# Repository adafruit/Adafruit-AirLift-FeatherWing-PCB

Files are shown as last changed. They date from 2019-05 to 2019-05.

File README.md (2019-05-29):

# Adafruit-AirLift-FeatherWing-PCB
PCB files for Adafruit AirLift FeatherWing

Format is EagleCAD schematic and board layout

For more details, check out the product page at

   * https://www.adafruit.com/product/4264

Adafruit invests time and resources providing this open source design, 
please support Adafruit and open-source hardware by purchasing 
products from Adafruit!

Designed by Adafruit Industries.  
Creative Commons Attribution, Share-Alike license, check license.txt for more information
All text above must be included in any redistribution

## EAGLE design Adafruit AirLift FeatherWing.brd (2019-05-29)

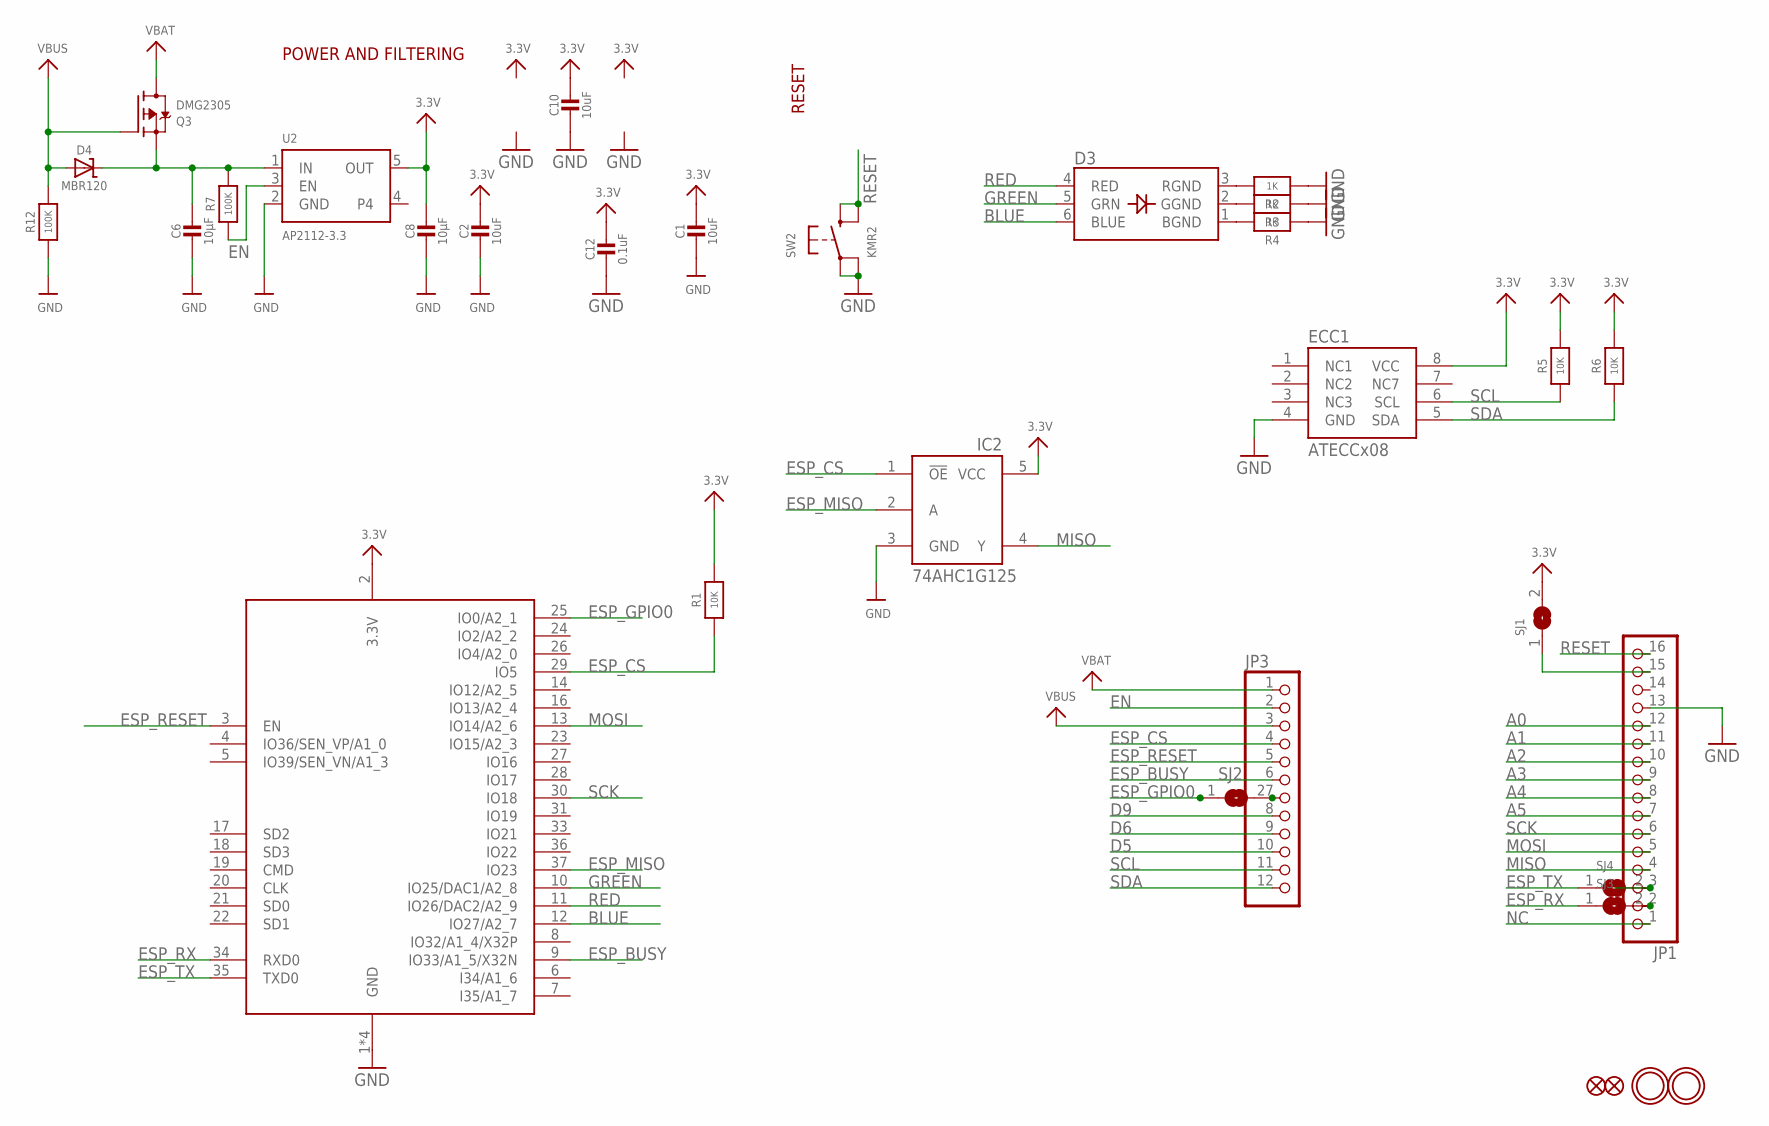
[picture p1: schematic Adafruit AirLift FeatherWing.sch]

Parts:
C1, C2, C10: 10uF; 0805-NO
C6, C8: 10µF; 0805-NO
C12: 0.1uF; 0603-NO
D3: LED_RGB_PLCC6CREE-CLV6A; RGBLED_PLCC6
D4: MBR120; SOD-123
ECC1: ATECCx08; SOIC8
IC2: 74AHC1G125; SOT23-5L
JP1: HEADER-1X16_MIN; 1X16_ROUND_MIN
JP3: HEADER-1X12_MIN; 1X12_ROUND_MIN
Q3: DMG2305; SOT23-R
R1, R5, R6: 10K; 0603-NO
R2, R3, R4: 1K; 0603-NO
R7, R12: 100K; 0603-NO
SJ1, SJ2, SJ3, SJ4: SOLDERJUMPER; SOLDERJUMPER_ARROW_NOPASTE
SW2: KMR2; BTN_KMR2_4.6X2.8
U2: AP2112-3.3; SOT23-5
U$31, U$32: MOUNTINGHOLE2.5; MOUNTINGHOLE_2.5_PLATED
U$34, U$35: FIDUCIAL_1MM
X3: ESP32_WROOM32_SKINNY; WROOM32_SKINNY

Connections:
3.3V: C1.1, C2.1, C8.1, C10.1, C12.1, ECC1.8 (VCC), IC2.5 (VCC), R1.2, R5.2, R6.2, SJ1.2, U2.5 (OUT), X3.2 (3.3V)
A0: JP1.12
A1: JP1.11
A2: JP1.10
A3: JP1.9
A4: JP1.8
A5: JP1.7
BLUE: D3.6 (BLUE), X3.12 (IO27/A2_7)
D5: JP3.10
D6: JP3.9
D9: JP3.8
EN: JP3.2, R7.1, U2.3 (EN)
ESP_BUSY: JP3.6, X3.9 (IO33/A1_5/X32N)
ESP_CS: IC2.1 (!OE), JP3.4, R1.1, X3.29 (IO5)
ESP_GPIO0: SJ2.1, X3.25 (IO0/A2_1)
ESP_MISO: IC2.2 (A), X3.37 (IO23)
ESP_RESET: JP3.5, X3.3 (EN)
ESP_RX: SJ3.1, X3.34 (RXD0)
ESP_TX: SJ4.1, X3.35 (TXD0)
GND: C1.2, C2.2, C6.2, C8.2, C10.2, C12.2, ECC1.4 (GND), IC2.3 (GND), JP1.13, R2.1, R3.1, R4.1, R12.1, SW2.A, SW2.A' (P1), U2.2 (GND), X3.1 (GND), X3.15 (GND), X3.38 (GND), X3.P$1 (GND)
GREEN: D3.5 (GRN), X3.10 (IO25/DAC1/A2_8)
MISO: IC2.4 (Y), JP1.4
MOSI: JP1.5, X3.13 (IO14/A2_6)
unnamed: JP1.15, SJ1.1
unnamed: D3.3 (RGND), R2.2
unnamed: D3.2 (GGND), R3.2
unnamed: D3.1 (BGND), R4.2
unnamed: JP3.7, SJ2.2
unnamed: JP1.2, SJ3.2
unnamed: C6.1, D4.C, Q3.2 (S), R7.2, U2.1 (IN)
unnamed: JP1.3, SJ4.2
NC: JP1.1
RED: D3.4 (RED), X3.11 (IO26/DAC2/A2_9)
RESET: JP1.16, SW2.B (S), SW2.B' (S1)
SCK: JP1.6, X3.30 (IO18)
SCL: ECC1.6 (SCL), JP3.11, R5.1
SDA: ECC1.5 (SDA), JP3.12, R6.1
VBAT: JP3.1, Q3.3 (D)
VBUS: D4.A, JP3.3, Q3.1 (G), R12.2

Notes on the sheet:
POWER AND FILTERING
RESET

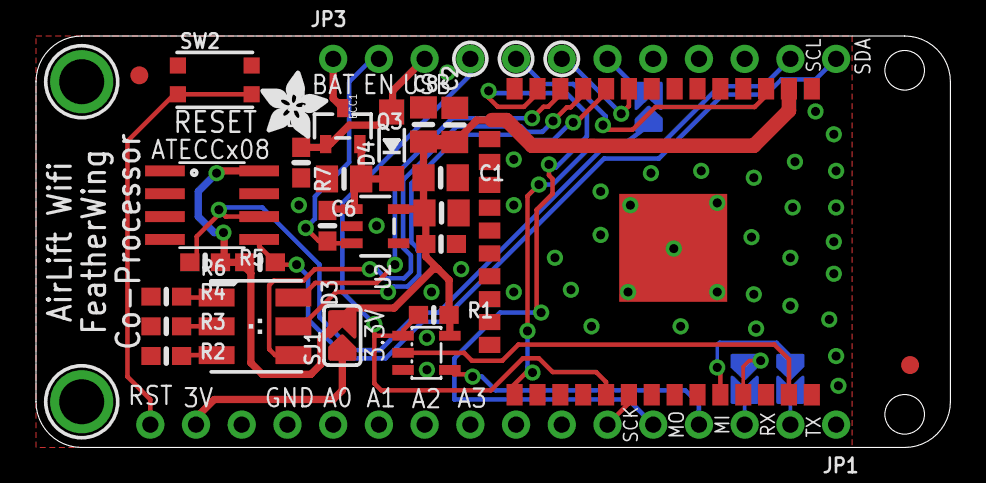
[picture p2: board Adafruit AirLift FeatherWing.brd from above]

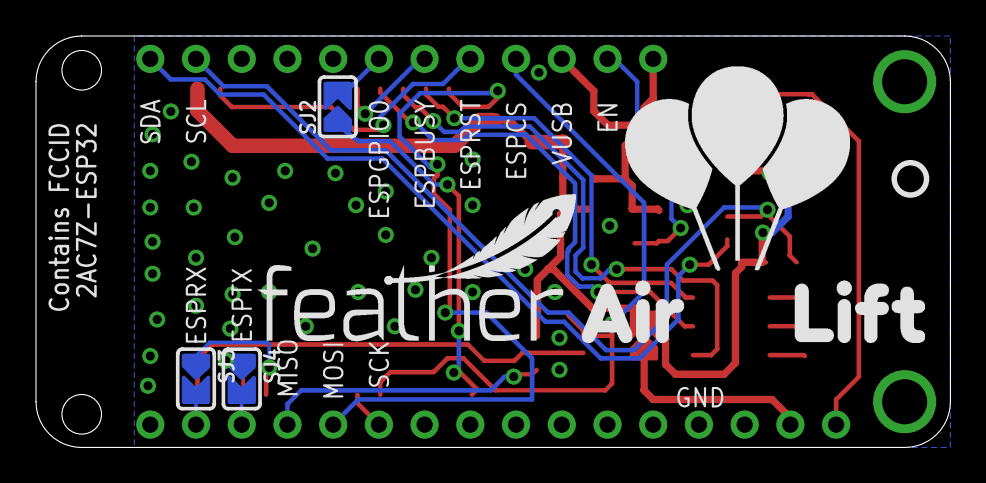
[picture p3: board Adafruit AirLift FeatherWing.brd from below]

Board: 2 copper layers, 50.8 x 22.9 mm, 36 parts (6 on the bottom side), 29 nets.

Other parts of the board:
U$6: AIRLIFT
U$7: FEATHERLOGO_MED
U$13: PCBFEAT-REV-040
U$15: ADAFRUIT_3.5MM

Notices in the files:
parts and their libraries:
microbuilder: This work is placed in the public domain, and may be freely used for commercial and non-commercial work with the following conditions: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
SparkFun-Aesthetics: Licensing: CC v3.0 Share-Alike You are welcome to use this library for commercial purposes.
